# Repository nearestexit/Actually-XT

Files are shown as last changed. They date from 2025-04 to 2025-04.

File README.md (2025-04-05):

# Actually-XT

Tired of keyboards being called "XT" when all they have is two macro columns on the left? Wishing for an authentic XT Layout experience? Look no further!

Front

Designed in Onshape and EasyEDA.

**Case Source (Onshape):** https://cad.onshape.com/documents/8e64c542934f3b3028105d41/w/e015a6267a64cee596c1d6b1/e/0926f7df13bebdcb666367dc

**PCB Source (EasyEDA):**  https://oshwlab.com/taylorswift22/actually-xt-v2

## Design changes after prototype

* Changed weight screws from M4 to M3
* Increased clearance around daughterboard
* Changed PCB compatibility to support keycaps from NCR G80-0577

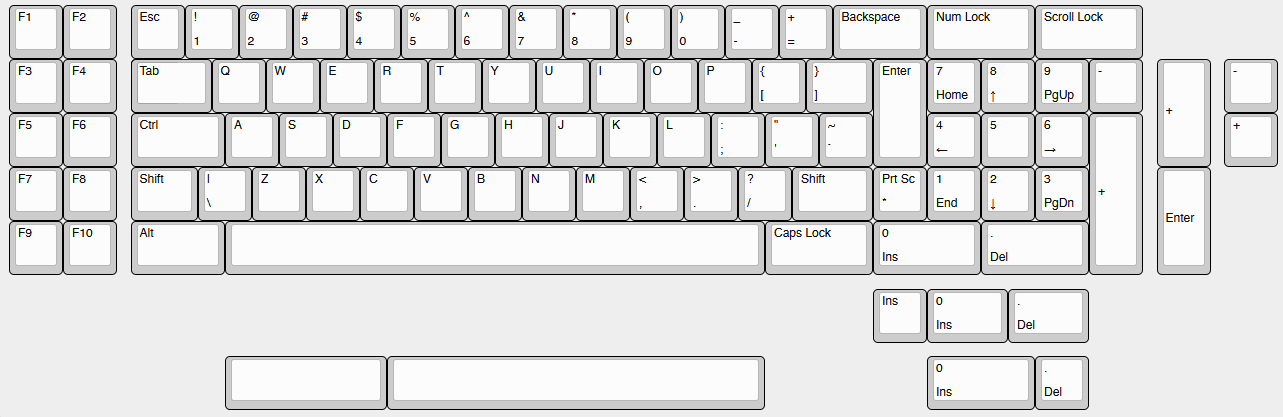
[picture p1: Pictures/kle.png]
KLE


## Bill of Materials

| Item  | Quantity | Link |
| --- | --- | --- |
| Unified Daughterboard  | 1  | https://cannonkeys.com/products/unified-daughterboard-and-jst-cable |
| M3x0.5x4mm Button Head Cap Screw | 2  | https://www.mcmaster.com/92095A471 |
| 10cm Molex to JST Cable | 1 | https://cannonkeys.com/products/unified-daughterboard-and-jst-cable |
| M3x0.5x5mm Countersunk Screw | 5 | https://www.mcmaster.com/91294A125 |
| M2x0.4x8mm Socket Head Cap Screw | 11 | https://www.mcmaster.com/91292A832 |
| M2x0.4x5mm Socket Head Cap Screw | 11 | https://www.mcmaster.com/91292A005 |

The 8mm M2 screws are for the case and the 5mm M2 screws are for the PCB. You can probably get away with 6mm M2 screws for both.

Back

Side

Please note: this project is for reference only.

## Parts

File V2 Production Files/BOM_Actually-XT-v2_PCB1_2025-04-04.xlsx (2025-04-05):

No. | Quantity | Comment | Designator | Footprint | Value | Manufacturer Part | Manufacturer | Supplier Part | Supplier
1 | 4 | 100nF | C1,C2,C5,C14 | C0603 | 100nF | CC0603KRX7R9BB104 | YAGEO(国巨) | C14663 | LCSC
2 | 2 | 4.7uF | C4,C8 | C0603 | 4.7uF | CL10A475KO8NNNC | SAMSUNG(三星) | C19666 | LCSC
3 | 3 | 1uF | C11,C12,C13 | C0805 | 1uF | CL21B105KBFNNNE | SAMSUNG(三星) | C28323 | LCSC
4 | 1 | SM04B-SRSS-TB(LF)(SN) | CN6 | CONN-SMD_4P-P1.00_SM04B-SRSS-TB-LF-SN |  | SM04B-SRSS-TB(LF)(SN) | JST | C160404 | LCSC
5 | 88 | 1N4148W | D1,D2,D3,D4,D5,D6,D7,D8,D9,D10,D11,D12,D13,D14,D15,D16,D17,D18,D19,D20,D21,D22,D23,D24,D25,D26,D27,D28,D29,D30,D31,D32,D33,D34,D35,D36,D37,D38,D39,D40,D41,D42,D43,D44,D45,D46,D47,D48,D49,D50,D51,D52,D53,D54,D55,D57,D58,D59,D60,D61,D62,D63,D64,D65,D66,D67,D68,D69,D70,D71,D72,D73,D74,D75,D76,D77,D78,D79,D80,D81,D82,D83,D85,D89,D95,D97,D98,D99 | SOD-123F_L2.7-W1.6-LS3.8-RD |  | 1N4148W | ST(先科) | C81598 | LCSC
7 | 1 | 10kΩ | R19 | R0805 | 10kΩ | 0805W8F1002T5E | UNI-ROYAL(厚声) | C17414 | LCSC
17 | 1 | STM32F072CBT6 | U1 | LQFP-48_L7.0-W7.0-P0.50-LS9.0-BL |  | STM32F072CBT6 | ST(意法半导体) | C81720 | LCSC
18 | 1 | XC6206P332MR-G | U2 | SOT-23-3_L2.9-W1.6-P1.90-LS2.8-BR |  | XC6206P332MR-G | TOREX(特瑞仕) | C5446 | LCSC

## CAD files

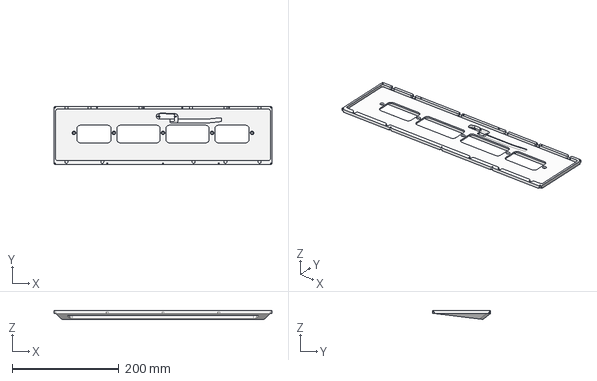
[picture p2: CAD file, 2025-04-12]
V2 Production Files/Bottom Case.step
409.0 x 108.5 x 16.7 mm

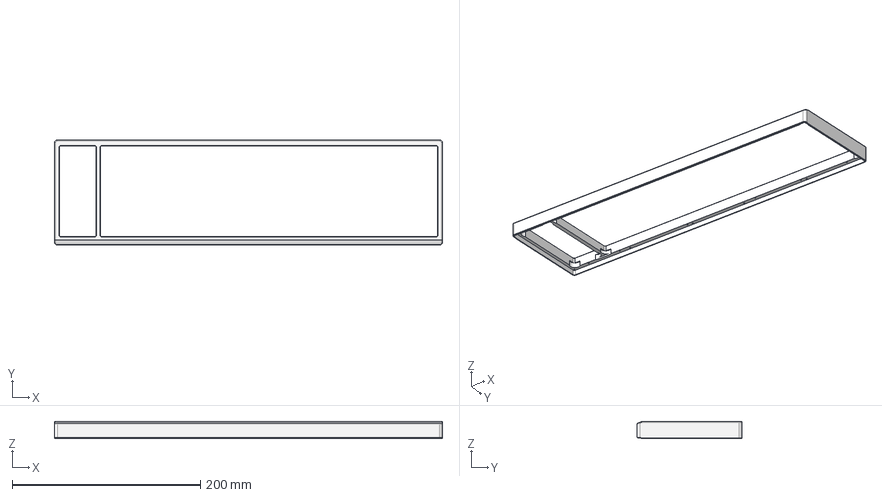
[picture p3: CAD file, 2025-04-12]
V2 Production Files/Top Case.step
412.0 x 111.5 x 18.3 mm

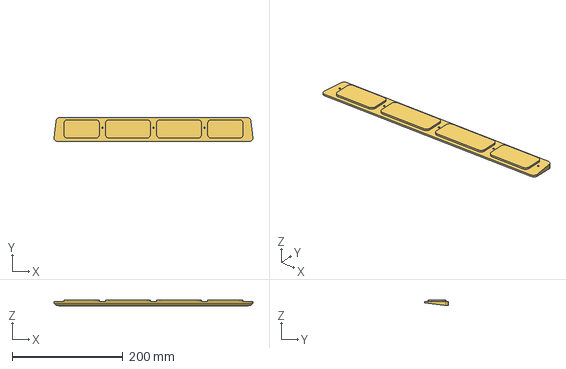
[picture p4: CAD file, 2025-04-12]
V2 Production Files/Weight.step
358.6 x 42.8 x 9.95 mm

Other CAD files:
V2 Production Files/Drawing - Top Case.dxf
V2 Production Files/Drawing - Bottom Case.dxf
V2 Production Files/Drawing - Weight.dxf
V1 Production Files/Top Case.step
V1 Production Files/Weight.step
V1 Production Files/Drawing - Bottom Case.dxf
V1 Production Files/Drawing - Weight.dxf
V1 Production Files/Drawing - Top Case.dxf
V1 Production Files/Bottom Case.step

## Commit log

2025-04-02 Add Production Files
    [BOM_Actually-XT_Schematic1_2025-03-18.xlsx, Bottom Case.step, Drawing - Bottom Case.dxf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]
2025-04-05 v2 production files
    [BOM_Actually-XT-v2_PCB1_2025-04-04.xlsx, BOM_Actually-XT_Schematic1_2025-03-18.xlsx, Bottom Case.step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]
